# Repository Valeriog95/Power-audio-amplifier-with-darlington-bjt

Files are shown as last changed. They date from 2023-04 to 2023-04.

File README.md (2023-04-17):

# Power-audio-amplifier-with-darlington-bjt

Hello everyone,
This repository shows a base amplifier made with only discrete components (without op-amp), it provides 25 watt  @ 8ohm.

I completed this project at 18 for my high school exam at ITIS Enrico Fermi institute in Rome and have made no changes since (relation remained in its original language). Later on, i created the board (using KiCad 5.0) and tested it using an electronic load and a signal generator/analyzer keithley2015.

Some features:

- More than 60% efficiency;
- THD less than 0.03% @ 1 watt;
- S/N > 85dB;

I'm open to any critiques/suggestions.

Hope that this simple project is helpful!

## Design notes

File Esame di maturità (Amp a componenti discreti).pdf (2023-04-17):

# Progetto Maturità: Amplificatore Audio a componenti discreti 25 watt RMS x 2 @ 8 ohm

Per progettare un amplificatore audio a componenti discreti, una volta stabilita la potenza, bisogna prima progettare il suo alimentatore, per fare ciò bisogna calcolare innanzitutto la sua tensione di alimentazione. Poiché la potenza RMS è data dalla tensione di alimentazione diviso due volte il carico (8 OHM) si avrà :
Prms=( Vcc)^2 /2R
Ppicco o musicale = (Vcc)^2 /R
La prima è la potenza basata sull’ effetto joule data dal valore assoluto della semionda, quindi la potenza reale, la seconda è la potenza di picco , data dal valore di picco della semionda ( verrà considerata solo la potenza RMS, ma è stato spiegato anche cos’è la potenza musicale, poiché essa viene riportata in molti amplificatori).
Alla tensione di alimentazione si dovrà aggiungere oltre alla tensione che cade effettivamente sul carico, anche la caduta di tensione sui transistor finali e sulle resistenze di stabilizzazione termica dei finali. La prima si trova sul datasheet e corrisponde, nei casi più estremi alla sua Vce di saturazione, la seconda è standard e varia da circa 1/10 a 1/15 della tensione di alimentazione, perciò la formula diventa :
Watt RMS = (Vcc –Vce-1/10Vcc)^2 / 2R
Per calcolare la tensione di alimentazione sono necessari alcuni passaggi algebrici : Watt RMS * 2R = (Vcc-Vce-1/10Vcc)^2
√(Watt RMS *2R) = Vcc-Vce-1/10Vcc
Come transistor finali si utilizzano i darlington bdx53c (NPN) e bdx53c (PNP) che presentano Vce sat 2,5V perciò :

√(25*16)=Vcc-2,5-1/10Vcc
20+2,5=Vcc-1/10Vcc
22,5=Vcc(1-1/10)
(22,5/9)*10=Vcc
Vcc=25V
La tensione di alimentazione sarà di 25 V continui. Perciò si sceglierà un trasfomatore con due secondari da 18 V poiché i 25 V sono in valore assoluto e per calcolare la tensione alternata, prima che sia raddrizzata si usa la seguente formula: Vcc/ √2 = Vcc /1.414 = 17.68 => +/- 18V
Normalmente la tensione di alimentazione degli amplificatori non va stabilizzata, poiché la potenza d’ uscita non è continua ma impulsiva, si mettono però valori di condensatori elevati, per ridurre il ripple quando lo stadio finale deve erogare una forte corrente, dell’ ordine ad esempio dei 10000uF.
La soluzione che ho adottato è quella di mettere due condensatori da 4700uF in parallelo anziché uno da 10000 uF perché così si ha un minor ESR.
La corrente massima che erogherà si verificherà nel caso di utilizzare due altoparlanti da 4 ohm e varrà :
Imax = 25/4*2= 3.125A
Poiché l’ amplificatore è a due canali la corrente è doppia quindi 6.25 A.
Per calcolare il ripple si usa la seguente formula:
DV = I / (2*f*C) = 6.25/ 2*50*0.0094= 6.65V
La massima ondulazione di segnale sarà 6.65, un ripple accettabile considerando che l’ amplificatore fornisce una corrente impulsiva, quindi il ripple sarà notevolmente ridotto.
I diodi del ponte raddrizzatore vanno scelti in base alla corrente media che li attraversa ovveero I/2 = 3,125.

Poiché si usa un trasformatore a presa centrale (per ottenere la tensione duale), andranno utilizzati dei diodi con Vrrm (massima tensione inversa) di almeno il doppio della tensione di secondario ovvero di 18 V.
Il trasformatore dovrà avere una potenza pari o superio a quella fornita sul carico più quella dissipata dai transistor e dalle resistenze di emettitore :
quella dissipata dal transistor è data dalla sua VCE * Imax e vale 3*3,125 = 9,375 Watt
quella dissipata dalla resistenza è 1/10*VCC*Imax =7,812Watt (questo valore corrisponderà anche al valore della potenza nominale della resistenza)
Quella sul carico sarà di 50 watt nel caso di altoparlanti da 4 ohm.
Perciò la potenza totale è di: 50+7,812+9,375=67,187Watt
Valore che va moltiplicato per 2 visto che l’ amplificatore è a due canali : 67,187 *2 = 134,37 watt, il trasformatore andrebbe preso maggiorato, da 150 watt poiché una minima potenza viene dissipata anche dagli stadi precedenti e dal relè di ritardo per gli altoparlanti. Il circuito dell’ alimentatore sarà perciò il seguente :

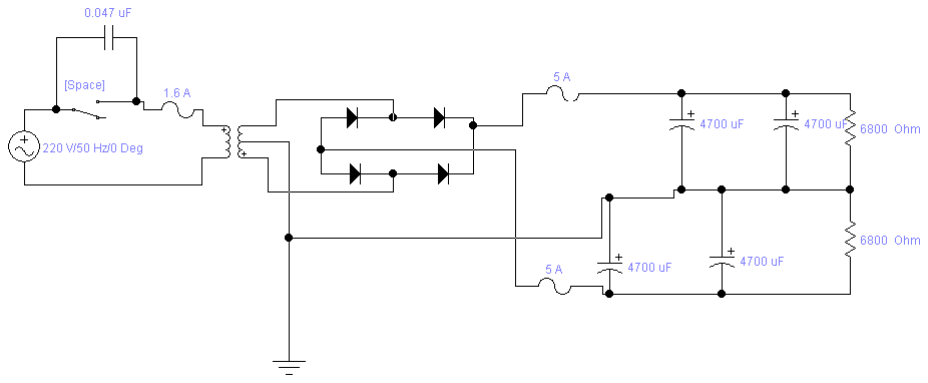
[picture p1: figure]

Le resistenze ai capi dei condensatori servono a scaricarli una volta spento l’ amplificatore.
Ora si passa alla progettazione del circuito di ritardo per gli altoparlanti.

Gli altoparlanti vanno infatti accesi con un leggero ritardo poiché altrimenti all’ accensione si sentirebbe un forte botto dovuto all’ eccessiva corrente per caricare i condensatori. Per rimediare a questo inconveniente, si usa mettere un circuito con un relay che ritardi l’ accensione dell’ uscita.
Poiché il relay funziona a 12 volt, si farà uso dell’ integrato LM7812 per ottenere questa tensione stabilizzata. Mentre il circuito di ritardo è il seguente:

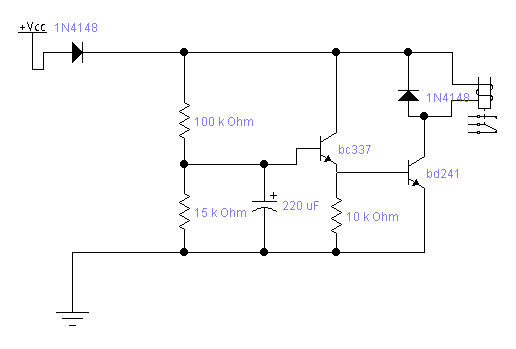
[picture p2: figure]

Il funzionamento del circuito è molto semplice, il condensatore da 220uF, inizialmente scarico, si caricherà e manderà in conduzione prima il transistor uno e successivamente il secondo.
La relazione che lega il tempo di carica a 1,4 V (tensione di conduzione di entrambi i transistor, poiché Vbe =0,7 V) .
Per trovare il tempo di accensione del relay basta calcolare la costante di tempo del circuito.
Il condensatore inizialmente scarico ci metterà per arriva a 1,5 V il tempo dettato dalla seguente relazione :
T=R*C*ln( (Vfin-Vin)/(Vfin-Vt))
Dove R e C sono la costante di tempo e vale : 22s

Dove Vfin è la tensione a cui tende il condensatore, ovvero Vcc-Vdiodo=11,3 V Vin è la tensione iniziale del condensatore (0V)
Vt è la tensione che deve raggiungere il condensatore nel lasso di tempo stabilito (1,4V).
Sostituendo a R e C la costante di tempo si otterrà un tempo di carica di :
T= 22 ln 11.3/(11.3-1,4) = 22 ln 1.141 =22*0.132=2.9s
Gli altoparlanti verranno accesi con circa 3 secondi di ritardo.
Passiamo ora a progettare l' amplificatore.
Un' amplificatore audio può essere paragonato ad un potente operazionale, deve perciò avere: resistenza di ingresso infinita, resistenza d' uscita nulla, guadagno in banda passante infinito. Per fare ciò dovrà avere :
1° stadio : stadio d' ingresso differenziale
2° stadio : stadio di amplificazione
3° stadio : stadio d' uscita o buffer di corrente
Il primo consiste in un differenziale a transistor e presenta elevata resistenza d ingresso e ingresso differenziale (un fattore importante che ci permetterà di reazionare negativamente l' amplificatore), nonché il primo stadio gode di una modesta amplificazione. Tra il primo stadio e quello di amplificazione che sarà un transistor a emettitore comune, ci sarà un altro transistor “buffer” connesso come collettore comune a disaccoppiare il primo stadio dal secondo. Questo buffer si ripeterà tra il 2 e il terzo stadio ma con una piccola modifica, sull' emettitore del secondo buffer ci sarà un circuito chiamato moltiplicatore di Vbe che servirà per polarizzare a riposo i finali e farli lavorare in classe AB. L' ultimo stadio è composto da due darlington con resistenze di stabilizzazione termica per i finali connessi in push-pull (ovver il transistor NPN amplificherà la sola semionda positiva mentre quello PNP amplificherà la negativa).
Per il primo stadio, il secondo e lo stadio pilota sarà necessario un generatore di corrente costante. Per avere un generatore di corrente costante bisogna polarizzare un transistor. Il circuito è il seguente e sul collettore si avrà l' uscita in corrente :

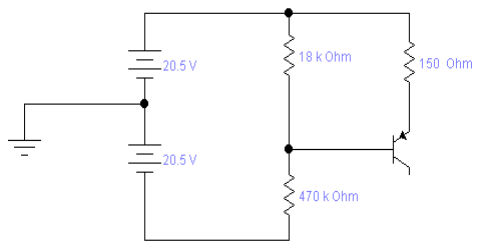
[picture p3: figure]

Il transistor che si userà è il BC 327 e presenta per un Ic = 10mA un Hfe di 100. Perciò la corrente di base sarà Ib = Ic/Hfe =0,10mA quindi la resistenza nel primo ramo sarà (25,5- (-25,5))/Ib = 510kohm
per la prima resistenza bisogna avere una tensione molto bassa, per aumentare la dinamica dell' amplificatore, perciò scegliamo 2V, quindi il valore della resistenza sarà :
R1 = 510000 * 2/51=20000 = valore standard 18kohm
R2 = 425000*49/51=490k= valore standard 470kohm
ora poiché su R1 ci sono circa due volt sulla resistenza di emettitore ci saranno i due volt meno la Vbe del transistor che è circa 0,7. La relazione che lega Ie è :
Ie=Ib+Ic poiché Ib è trascurabile rispetto a Ic, Ie=Ic da cui segue che Re = Ve/Ie
Re = 1.3/0,010=130 ohm valore standard 150 ohm.
Questo circuito che eroga una corrente costante di 0,01mA andrà bene per tutti gli stadi, infatti per l' ultimo sono necessari, per pilotare i darlington, almeno Imax/Hfe=3,15/1000=3,15mA, perciò i 10 mA del generatore sono sufficienti a permettere ai finali di erogare tutta la corrente necessaria.

Il circuito finale è quello presentato in figura

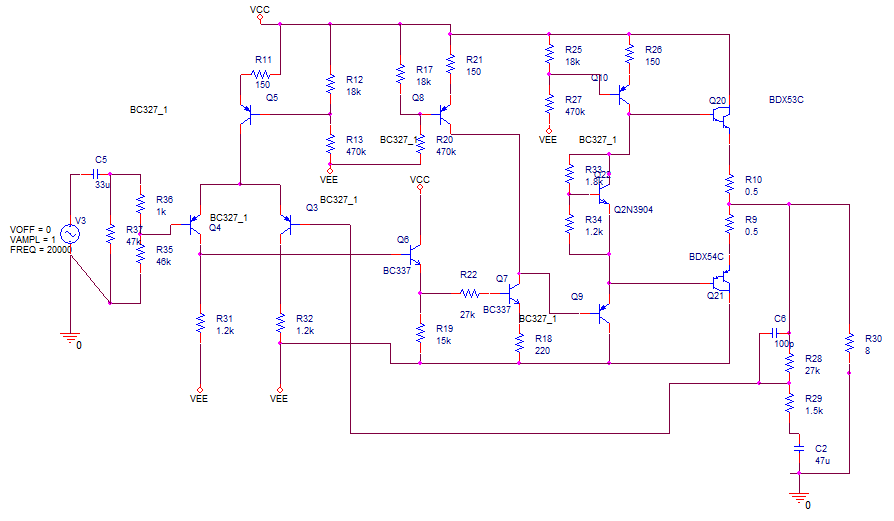
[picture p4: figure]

in alto ci sono i 3 generatori di corrente costante e sotto in ordine c'è il differenziale di ingresso con R31 e R32 come resistenze di carico del differenziale e vanno calcolate ponendo su di loro una piccola caduta di potenziale, in modo da avere la maggior dinamica possibile. Ponendo ad esempio 4,5volt si avrà una resistenza di :

4,5/Ie/2=4,5/0.0035=1285ohm, valore standard 1.2k
la caduta di tensione su R31 sarà la stessa di R19 meno la Vbe del transistor, quindi sarà di 4,5-0,7=3,8V per avere una corrente basse nello stadio di buffer (0,25mA) varrà la legge di ohm :
R31 = VR31/0,25mA= 15200ohm valore standard 15k.

Ora nello stadio di guadagno si pone un valore di tensione molto basso su R18 ( in modo da aumentare la dinamica d' uscita), scegliamo 2 Volt e la corrente è data dal generatore di corrente costante che corrisponde a 0,007mA.
R18 = 2/0,0075 = 266 ohm valore standard 220 ohm
per avere una corrente di base di circa Ic/100 =0,00007 si avrà una resistenza di base di :
3,8-2-0,7=1,1 V da cui segue che R22 = 1,1 / 0,00007 =15714 valore standard 15k Infine il moltiplicatore di Vbe serve per polarizzare i finali e farli lavorare in classe AB, altrimenti lavorerebbe in classe B ma si verificherebbe la distorsione di crossover, dovuta al fatto che i finali entrano in conduzione solamente con 0,7 volt tra base e emettitore perciò durante le semionde positive e negative del segnale, i transistor condurranno solo quando quest' ultimo supererà i 0,7 V ( che nel nostro caso saranno 1,4 perché i finali sono darlington.

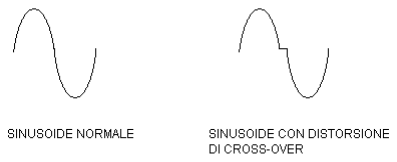
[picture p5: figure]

Per ovviare a questo inconveniente si può fare uso di diodi o di un circuito moltiplicatore di Vbe formato da un transistor polarizzato con due resistenze e alimentato da un generatore di corrente costante.
Il moltiplicatore di Vbe risulta migliore poiché inserendo un trimmer si può regolare con precisione la corrente che scorre nei finali a riposo che dovrà essere di circa 40mA. Inoltre montando il transistor sulla stessa aletta di raffreddamento o a contatto con i finali, si manterrà una perfetta linearità delle caratteristiche di uscita del transistor finale. Il circuito è quello presente in figura costituito da R33 (eun trimmer da 4,7k in serie a R33) e R34 e il transistor Q22.
Il moltiplicatore di Vbe presenta una resistenza tra base ed emettitore e una resistenza di retroazione tra base ee collettore, se si trascura la coorrente di base del transistor si avrà:

Ir = Vbe/R34
dove Ir è la corrente che scorre nel ramo delle resistenze.
La tensione sulla rete di polarizzazione sarà :
Vbb=Ir*(R34+R33) da cui segue infine che Vbb=Vbe*(1+R33/R34)
poiché i finali entrano in conduzione a circa 1,2 v per uno si avrà una Vbb di 2,4 perciò una R33 di 4R34, quindi essendo R34 di 1,2k R33 si aggirerà intorno a 4,8k che verrà regolata con precisione dal trimmer posto in serie a una resistenza da 1,8k. Infine ci vorranno due resistenze di emettitore, che assorbiranno circa 1/15 della tensione di alimentazione, per stabilizzare termicamente i transistor ed impedire la “fuga termica”. Perciò se la massima escursione è di Vcc- Vce Sat = 25,5 – 2,5 = 23V e la massima corrente è di 3.15 A si avrà una R di 23V / 3,15 A*1 /15 =0,486 ohm valore standard 0,47 ohm e dovrà dissipare una potenza di 23*3,15*1/15 = 4,83 watt.
Infine si stabilisce il guadagno che è dato da 1+ R28/R29 perciò sarà di 23,5
in DB è 20*log23,5 = 27DB
Per minimizzare l' offset si mette una resistenza tra l' ingresso e la massa, dello stesso valore di R28. Infine si calcolano le frequenze di taglio superiori e inferiori del circuito:
La frequenza di taglio passa basso è data da 1/2*3.14*R29*C2
è stato scelto come frequenza di taglio inferiore 3 Hz che sarà il polo dominante mentre il condensatore di ingresso bloccherà solo le componenti continui e avrà una frequenza molto inferiore.
C2 varrà a questo punto :
1/6.28*3*1500 = 35uF valore standard 33uF
Usando lo stesso valore del condensatore anche per l' ingresso si avrà una ft inferiore di :
1/R28*C2*6,28= 0,18 heartz che può andare bene perchè è più piccola di almeno un fattore 10.

la frequenza di taglio superiore è data da 1/6,28*R28*C6
è stato scelto come valore 60 kHz (valore nettamente superiore alla banda di frequenze audio, ma 60khz bloccherà sia le radiofrequenze e non introdurrà rotazioni di fase nelle frequenze audio udibili). Quindi C6 varrà 1/60000*6,28*27000= 98p valore standard 100p
La progettazione dell' amplificatore è finita, una volta eseguita la simulazione su PSPICE e successivamente il collaudo su breadboard si potrà saldare su millefori o fare un piccolo PCB utilizzando appositi programmi di sbroglio .
Valerio Gregori

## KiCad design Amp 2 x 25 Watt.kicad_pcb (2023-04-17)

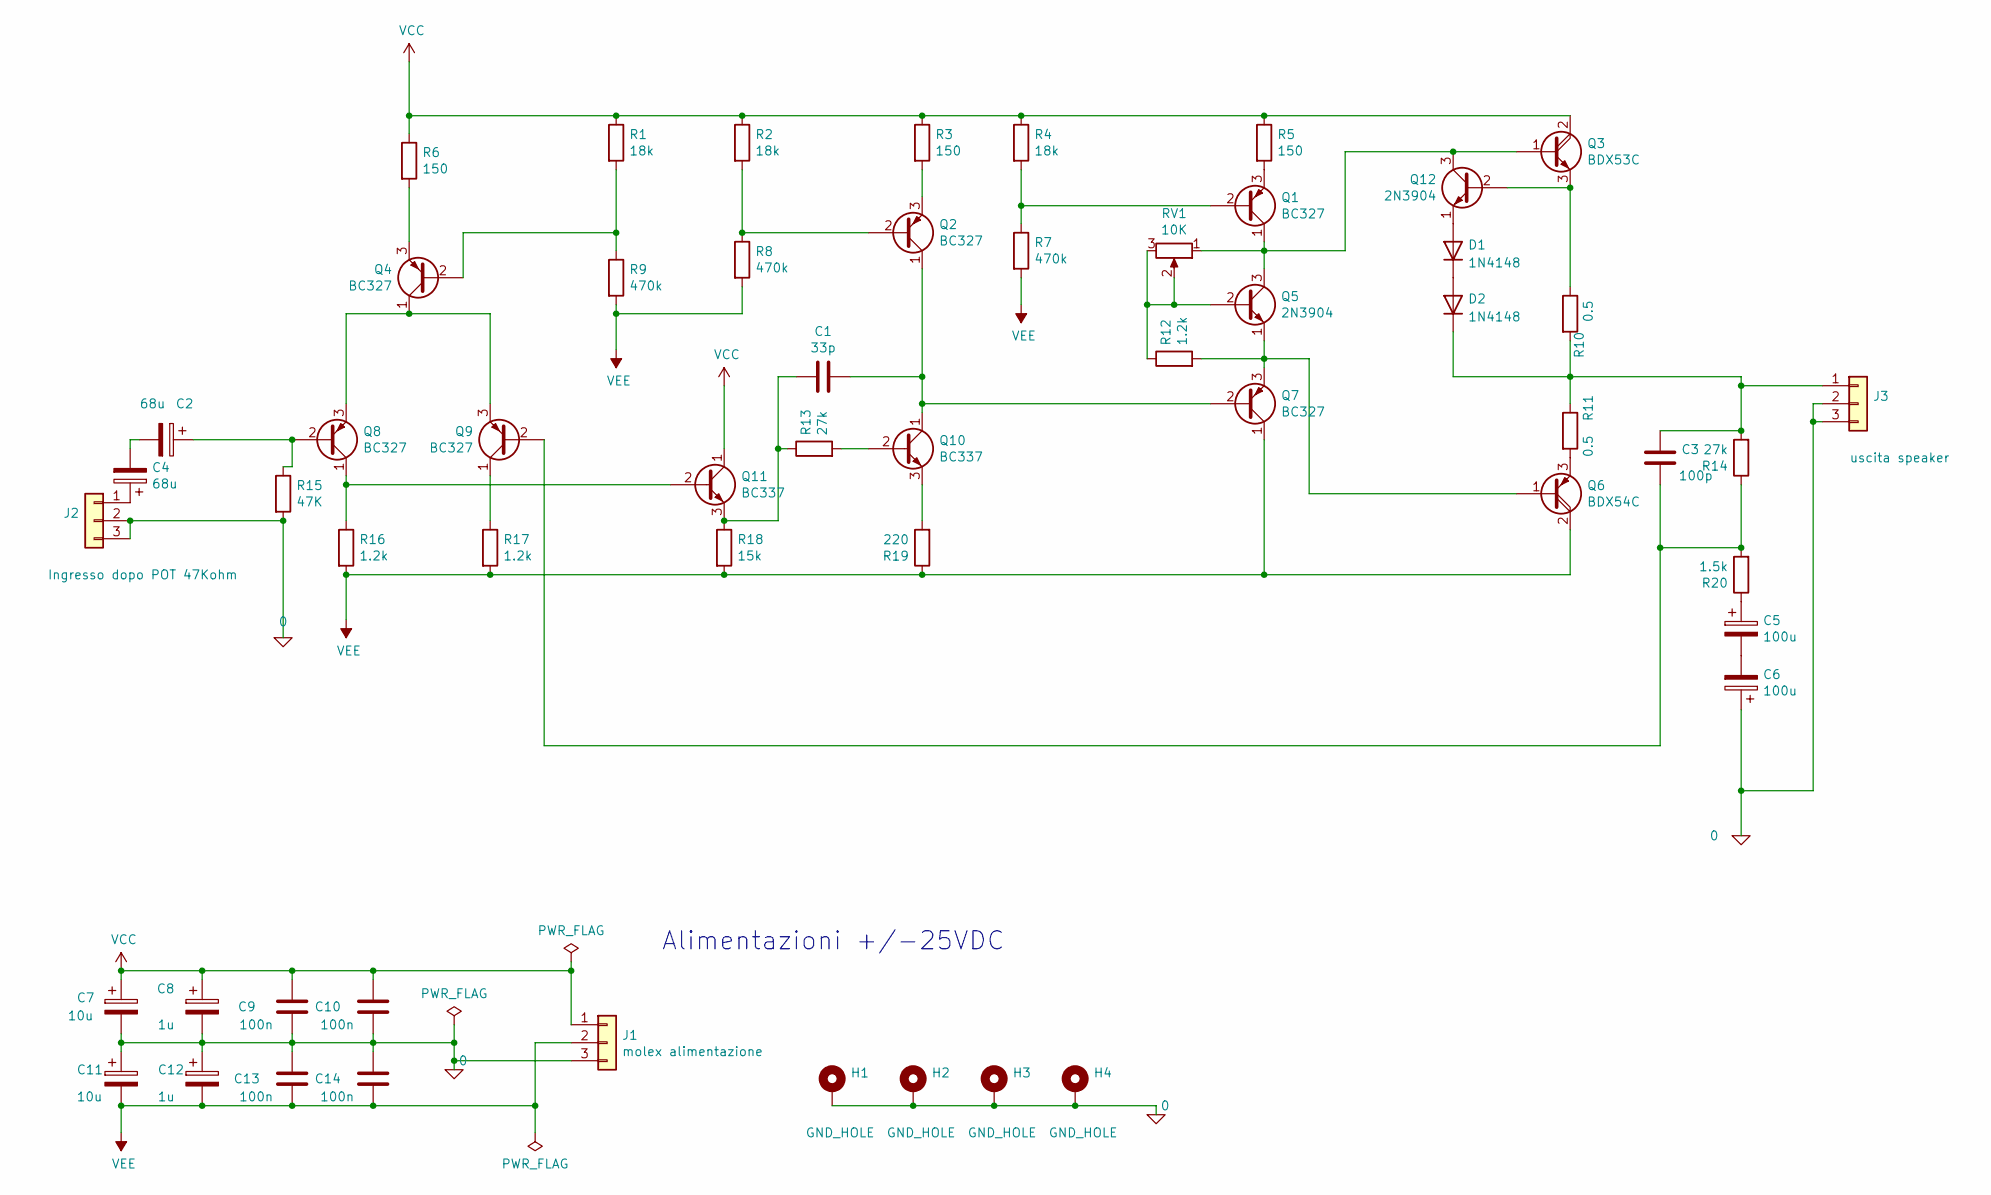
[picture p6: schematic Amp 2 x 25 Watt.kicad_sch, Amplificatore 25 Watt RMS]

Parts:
C1: 33p; C_Disc_D7.0mm_W2.5mm_P5.00mm
C2, C4: 68u; CP_Radial_D6.3mm_P2.50mm
C3: 100p; C_Disc_D7.0mm_W2.5mm_P5.00mm
C5, C6: 100u; CP_Radial_D8.0mm_P3.50mm
C7, C11: 10u; CP_Radial_D5.0mm_P2.00mm
C8, C12: 1u; CP_Radial_D5.0mm_P2.50mm
C9, C10, C13, C14: 100n; C_Rect_L7.2mm_W5.5mm_P5.00mm_FKS2_FKP2_MKS2_MKP2
D1, D2: 1N4148; D_DO-35_SOD27_P7.62mm_Horizontal
H1, H2, H3, H4: GND_HOLE; MountingHole_3.2mm_M3_DIN965_Pad_TopBottom
J1: molex alimentazione; Connectors_threeway
J2: Ingresso dopo POT 47Kohm; Connectors_threeway
J3: uscita speaker; Connectors_threeway
Q1, Q2, Q4, Q7, Q8, Q9: BC327; TO-92_Inline
Q3: BDX53C; TO-220-3_Vertical
Q5, Q12: 2N3904; TO-92_Inline
Q6: BDX54C; TO-220-3_Vertical
Q10, Q11: BC337; TO-92_Inline
R1, R2, R4: 18k; R_Axial_DIN0207_L6.3mm_D2.5mm_P10.16mm_Horizontal
R3, R5, R6: 150; R_Axial_DIN0207_L6.3mm_D2.5mm_P10.16mm_Horizontal
R7, R8, R9: 470k; R_Axial_DIN0207_L6.3mm_D2.5mm_P10.16mm_Horizontal
R10, R11: 0.5; R_Axial_Power_L25.0mm_W6.4mm_P27.94mm
R12, R16, R17: 1.2k; R_Axial_DIN0207_L6.3mm_D2.5mm_P10.16mm_Horizontal
R13, R14: 27k; R_Axial_DIN0207_L6.3mm_D2.5mm_P10.16mm_Horizontal
R15: 47K; R_Axial_DIN0207_L6.3mm_D2.5mm_P10.16mm_Horizontal
R18: 15k; R_Axial_DIN0207_L6.3mm_D2.5mm_P10.16mm_Horizontal
R19: 220; R_Axial_DIN0207_L6.3mm_D2.5mm_P10.16mm_Horizontal
R20: 1.5k; R_Axial_DIN0207_L6.3mm_D2.5mm_P10.16mm_Horizontal
RV1: 10K; Potentiometer_ACP_CA9-V10_Vertical

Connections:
0: C6.1, C7.2, C8.2, C9.2, C10.2, C11.1, C12.1, C13.1, C14.1, H1.1, H2.1, H3.1, H4.1, J1.3, J2.2, J2.3, J3.2, J3.3, R15.2
unnamed: C1.1, Q2.1 (C), Q7.2 (B), Q10.1 (C)
unnamed: C1.2, Q11.3 (E), R13.1, R18.1
unnamed: C2.1, Q8.2 (B), R15.1
unnamed: C2.2, C4.2
unnamed: C3.1, D2.1 (K), J3.1, R10.2, R11.1, R14.2
unnamed: C3.2, Q9.2 (B), R14.1, R20.2
unnamed: C4.1, J2.1
unnamed: C5.1, R20.1
unnamed: C5.2, C6.2
unnamed: D1.1 (K), D2.2 (A)
unnamed: D1.2 (A), Q12.1 (E)
unnamed: Q1.1 (C), Q3.1 (B), Q5.3 (C), Q12.3 (C), RV1.1
unnamed: Q1.2 (B), R4.2, R7.1
unnamed: Q1.3 (E), R5.2
unnamed: Q2.2 (B), R2.2, R8.1
unnamed: Q2.3 (E), R3.2
unnamed: Q4.1 (C), Q8.3 (E), Q9.3 (E)
unnamed: Q4.2 (B), R1.2, R9.1
unnamed: Q4.3 (E), R6.2
unnamed: Q5.1 (E), Q6.1 (B), Q7.3 (E), R12.2
unnamed: Q5.2 (B), R12.1, RV1.2, RV1.3
unnamed: Q6.3 (E), R11.2
unnamed: Q9.1 (C), R17.1
unnamed: Q10.2 (B), R13.2
unnamed: Q10.3 (E), R19.2
unnamed: Q8.1 (C), Q11.2 (B), R16.1
unnamed: Q3.3 (E), Q12.2 (B), R10.1
VCC: C7.1, C8.1, C9.1, C10.1, J1.1, Q3.2 (C), Q11.1 (C), R1.1, R2.1, R3.1, R4.1, R5.1, R6.1
VEE: C11.2, C12.2, C13.2, C14.2, J1.2, Q6.2 (C), Q7.1 (C), R7.2, R8.2, R9.2, R16.2, R17.2, R18.2, R19.1

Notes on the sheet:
Alimentazioni +/-25VDC

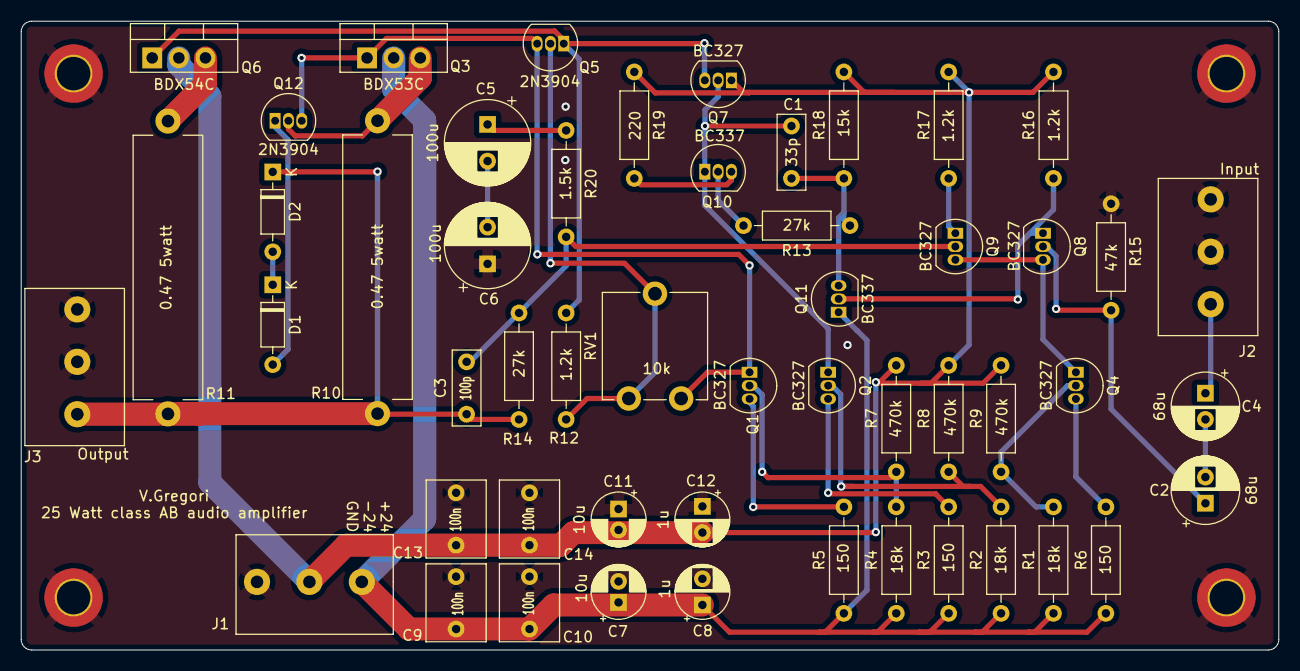
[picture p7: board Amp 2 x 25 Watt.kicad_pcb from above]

Board: 2 copper layers, 120.0 x 60.0 mm, 56 parts (0 on the bottom side), 30 nets.
